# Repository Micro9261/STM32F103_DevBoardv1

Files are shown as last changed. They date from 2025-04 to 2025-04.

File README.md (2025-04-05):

First fully developed boards in KiCad that gives opportunity to use all GPIOS by using 2.54mm pins connector.
USB-C with 5V to 3V converter onboard for power supply with led indication.
External crystal oscillator with resistor and capacitor selected accordingly to STM32 design specification.
User button & led and reset button onboard.
Additional analog filter, created by using 100mH coil and 100pF capacitor. 
pcbView

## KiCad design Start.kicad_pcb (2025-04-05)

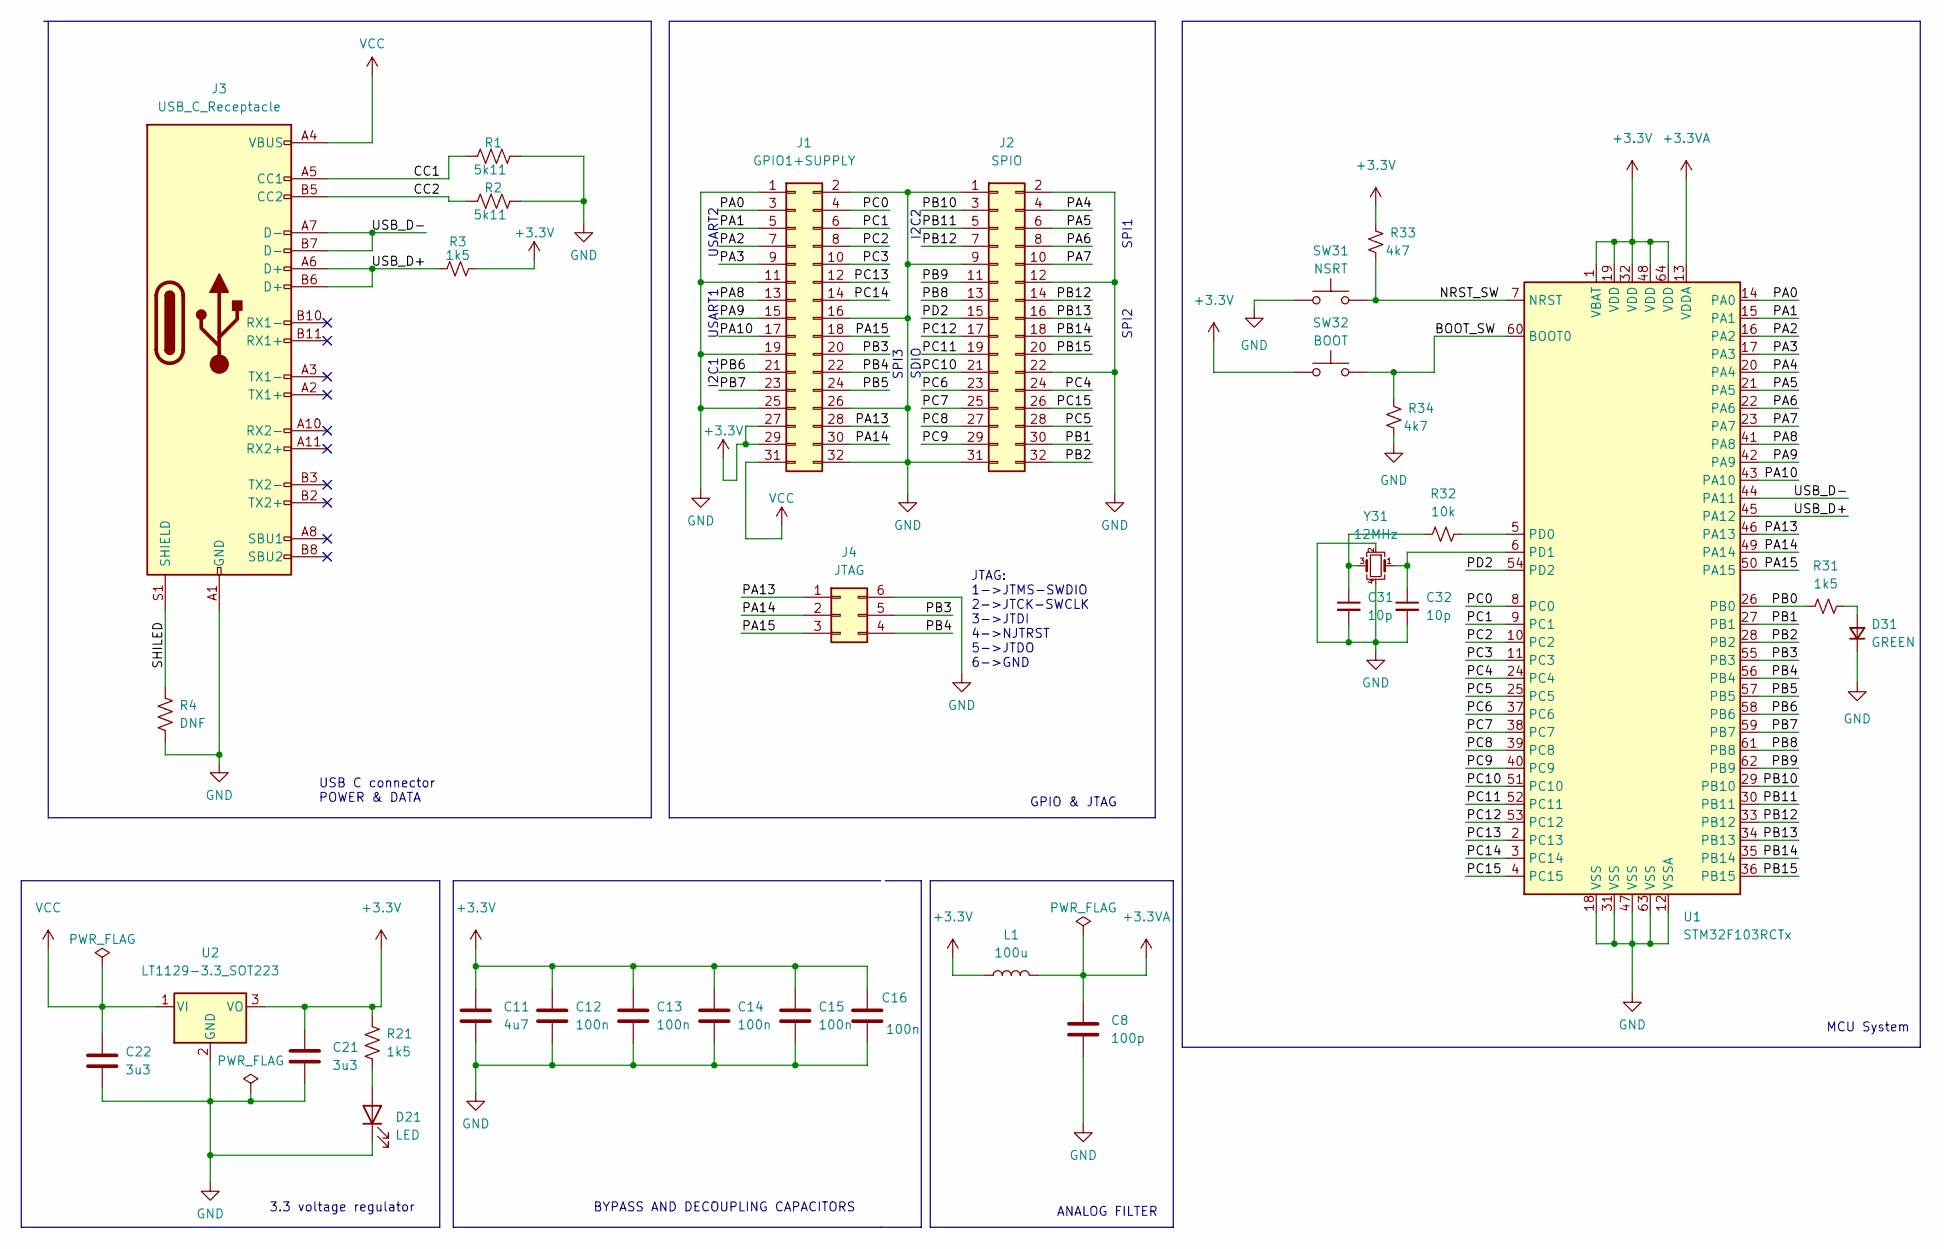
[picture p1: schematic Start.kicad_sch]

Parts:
C8: 100p; C_0402_1005Metric
C11: 4u7; C_0603_1608Metric
C12, C13, C14, C15, C16: 100n; C_0402_1005Metric
C21, C22: 3u3; C_0603_1608Metric
C31, C32: 10p; C_0402_1005Metric
D21: LED; D_0603_1608Metric
D31: GREEN; D_0603_1608Metric
J1: GPIO1+SUPPLY; PinHeader_2x16_P2.54mm_Vertical
J2: SPIO; PinHeader_2x16_P2.54mm_Vertical
J3: USB_C_Receptacle; USB_C_China
J4: JTAG; PinHeader_2x03_P2.54mm_Vertical
L1: 100u; L_0603_1608Metric
R1, R2: 5k11; R_0603_1608Metric
R3, R21, R31: 1k5; R_0603_1608Metric
R4: DNF; R_0603_1608Metric
R32: 10k; R_0603_1608Metric
R33, R34: 4k7; R_0603_1608Metric
SW31: NSRT; 3x4x2mm Switch Tactile
SW32: BOOT; 3x4x2mm Switch Tactile
U1: STM32F103RCTx; LQFP-64_10x10mm_P0.5mm
U2: LT1129-3.3_SOT223; SOT-223-3_TabPin2
Y31: 12MHz; Crystal_SMD_EuroQuartz_MT-4Pin_3.2x2.5mm

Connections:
+3.3V: C11.1, C12.1, C13.1, C14.1, C15.1, C16.1, C21.1, J1.27, J1.29, L1.1, R3.2, R21.1, R33.2, SW32.1, U1.1 (VBAT), U1.19 (VDD), U1.32 (VDD), U1.48 (VDD), U1.64 (VDD), U2.3 (VO)
+3.3VA: C8.1, L1.2, U1.13 (VDDA)
/BOOT_SW: R34.2, SW32.2, U1.60 (BOOT0)
/CC1: J3.A5 (CC1), R1.1
/CC2: J3.B5 (CC2), R2.1
/NRST_SW: R33.1, SW31.2, U1.7 (NRST)
/PA0: J1.3, U1.14 (PA0)
/PA1: J1.5, U1.15 (PA1)
/PA2: J1.7, U1.16 (PA2)
/PA3: J1.9, U1.17 (PA3)
/PA4: J2.4, U1.20 (PA4)
/PA5: J2.6, U1.21 (PA5)
/PA6: J2.8, U1.22 (PA6)
/PA7: J2.10, U1.23 (PA7)
/PA8: J1.13, U1.41 (PA8)
/PA9: J1.15, U1.42 (PA9)
/PA10: J1.17, U1.43 (PA10)
/PA13: J1.28, J4.1, U1.46 (PA13)
/PA14: J1.30, J4.2, U1.49 (PA14)
/PA15: J1.18, J4.3, U1.50 (PA15)
/PB0: R31.1, U1.26 (PB0)
/PB1: J2.30, U1.27 (PB1)
/PB2: J2.32, U1.28 (PB2)
/PB3: J1.20, J4.5, U1.55 (PB3)
/PB4: J1.22, J4.4, U1.56 (PB4)
/PB5: J1.24, U1.57 (PB5)
/PB6: J1.21, U1.58 (PB6)
/PB7: J1.23, U1.59 (PB7)
/PB8: J2.13, U1.61 (PB8)
/PB9: J2.11, U1.62 (PB9)
/PB10: J2.3, U1.29 (PB10)
/PB11: J2.5, U1.30 (PB11)
/PB12: J2.7, J2.14, U1.33 (PB12)
/PB13: J2.16, U1.34 (PB13)
/PB14: J2.18, U1.35 (PB14)
/PB15: J2.20, U1.36 (PB15)
/PC0: J1.4, U1.8 (PC0)
/PC1: J1.6, U1.9 (PC1)
/PC2: J1.8, U1.10 (PC2)
/PC3: J1.10, U1.11 (PC3)
/PC4: J2.24, U1.24 (PC4)
/PC5: J2.28, U1.25 (PC5)
/PC6: J2.23, U1.37 (PC6)
/PC7: J2.25, U1.38 (PC7)
/PC8: J2.27, U1.39 (PC8)
/PC9: J2.29, U1.40 (PC9)
/PC10: J2.21, U1.51 (PC10)
/PC11: J2.19, U1.52 (PC11)
/PC12: J2.17, U1.53 (PC12)
/PC13: J1.12, U1.2 (PC13)
/PC14: J1.14, U1.3 (PC14)
/PC15: J2.26, U1.4 (PC15)
/PD2: J2.15, U1.54 (PD2)
/SHILED: J3.S1 (SHIELD), R4.1
/USB_D+: J3.A6 (D+), J3.B6 (D+), R3.1, U1.45 (PA12)
/USB_D-: J3.A7 (D-), J3.B7 (D-), U1.44 (PA11)
GND: C8.2, C11.2, C12.2, C13.2, C14.2, C15.2, C16.2, C21.2, C22.2, C31.2, C32.2, D21.1 (K), D31.1 (K), J1.1, J1.2, J1.11, J1.16, J1.19, J1.25, J1.26, J1.32, J2.1, J2.2, J2.9, J2.12, J2.22, J2.31, J3.A1 (GND), J3.A12 (GND), J3.B1 (GND), J3.B12 (GND), J4.6, R1.2, R2.2, R4.2, R34.1, SW31.1, U1.12 (VSSA), U1.18 (VSS), U1.31 (VSS), U1.47 (VSS), U1.63 (VSS), U2.2 (GND), Y31.2, Y31.4
unnamed: C31.1, R32.1, Y31.3
unnamed: C32.1, U1.6 (PD1), Y31.1
unnamed: D21.2 (A), R21.2
unnamed: D31.2 (A), R31.2
unnamed: R32.2, U1.5 (PD0)
VCC: C22.1, J1.31, J3.A4 (VBUS), J3.A9 (VBUS), J3.B4 (VBUS), J3.B9 (VBUS), U2.1 (VI)

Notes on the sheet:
I2C1
SPI2
ANALOG FILTER
SDIO
USART2
3.3 voltage regulator
SPI1
USART1
BYPASS AND DECOUPLING CAPACITORS
MCU System
SPI3
USB C connector POWER & DATA
JTAG: 1->JTMS-SWDIO 2->JTCK-SWCLK 3->JTDI 4->NJTRST 5->JTDO 6->GND
I2C2
GPIO & JTAG

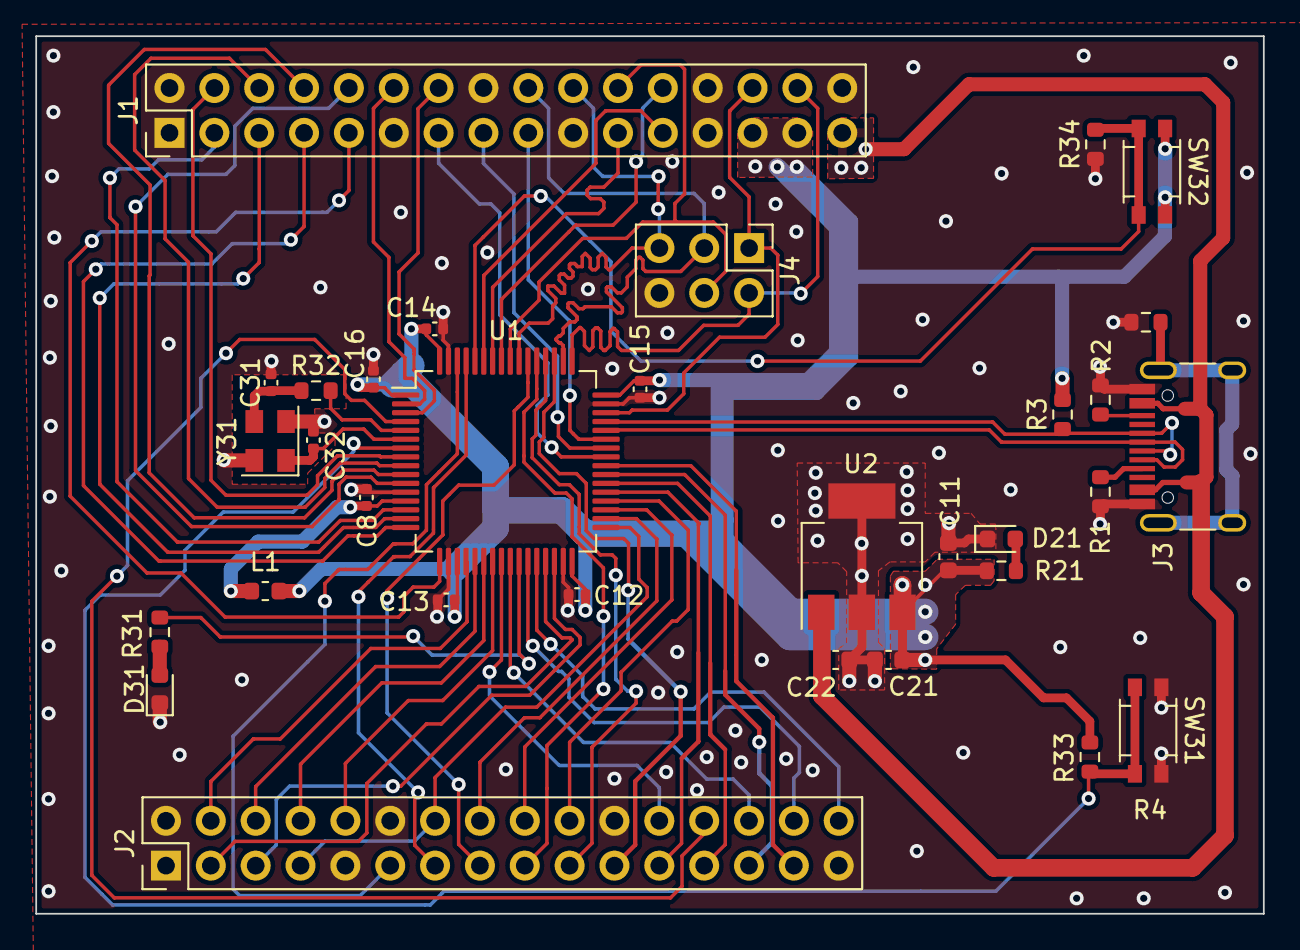
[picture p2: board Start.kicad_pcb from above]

Board: 2 copper layers, 69.5 x 49.7 mm, 32 parts (0 on the bottom side), 63 nets.
